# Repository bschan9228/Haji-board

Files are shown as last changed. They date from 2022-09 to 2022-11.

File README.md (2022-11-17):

# Haji Keyboard
The Haji keyboard uses 8-bit shift registers, rather than the typical keyboard matrix cirucit. An advantage in using shift registers is that you can add any amount of keys, instead of being limited by the amount of I/O pins. It uses an STM32F1 chip to communicate to a computer using its native USB interface. I sourced components, designed and fabricated the pcb, soldered, built, and programmed a fully working prototype of a small macropad from scratch.



##PARTS
NOTES:
HOTSWAPPABLE SWITCHES

ICS:
STM32F1
74HC165D,653

MODULES:
UNIFIED C3

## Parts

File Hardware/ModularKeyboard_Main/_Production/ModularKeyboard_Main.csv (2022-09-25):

Comment | Designator | Footprint | LCSC Part #
4.7uF Unpolarized capacitor, small symbol | C1 | C_0402_1005Metric | C189469
100nF Unpolarized capacitor, small symbol | C2,C3,C4,C5,C8 | C_0402_1005Metric | C83056
10nF Unpolarized capacitor, small symbol | C6 | C_0402_1005Metric | C60133
1uF Unpolarized capacitor, small symbol | C7 | C_0402_1005Metric | C92755
12p Unpolarized capacitor, small symbol | C9,C10 | C_0402_1005Metric | C106201
2.2uF Unpolarized capacitor, small symbol | C11,C12 | C_0402_1005Metric | C77002
MountingHole Mounting Hole without connection | H1,H2,H3,H4 | MountingHole_2.2mm_M2 | ~
16MHz Four pin crystal, GND on pins 2 and 4, small symbol | HSE1 | Crystal_SMD_3225-4Pin_3.2x2.5mm | C13738
Conn_01x03 Generic connector, single row, 01x03, script generated (kicad-library-utils/schlib/autogen/connector/) | J1,J2,J3,J4 | PG-3P-2.5 | ~
SM04B-SRSS-TB(LF)(SN) | J5,J6 | JST_SM04B-SRSS-TB(LF)(SN) | C160404
Mount-M2 Generic connector, single row, 01x01, script generated (kicad-library-utils/schlib/autogen/connector/) | MH1,MH2,MH3,MH4 | Generic-Mounthole
OLED | OL1 | OLED_v2 | ~
10k Resistor, small symbol | R1 | R_0402_1005Metric | C144807
22 Resistor, small symbol | R2,R3 | R_0402_1005Metric | C226359
1.5k Resistor, small symbol | R4 | R_0402_1005Metric | C144792
1k Resistor, small symbol | R5 | R_0402_1005Metric | C106235
DNP Resistor, small symbol | R6,R7 | R_0402_1005Metric | C106231
R_Pack04 4 resistor network, parallel topology | RN1,RN2,RN3,RN4 | R_Array_Convex_4x0402 | C326872
SW_SPST Single Pole Single Throw (SPST) switch | SW0,SW1,SW2,SW3,SW4,SW5,SW6,SW7,SW8,SW9,SW10,SW11,SW12,SW13,SW14,SW15 | MX-1U-NoLED | ~
SW_SPST Single Pole Single Throw (SPST) switch | SW16 | SW_SPST_B3U-1000P | C231329
74HC165D,653 | U1,U3 | SOIC127P600X175-16N | C5613
STM32F103CBTx ARM Cortex-M3 MCU, 128KB flash, 20KB RAM, 72MHz, 2-3.6V, 37 GPIO, LQFP-48 | U2 | LQFP-48_7x7mm_P0.5mm | C8304
SPX3819M5-L-3-3 500mA Low drop-out regulator, Fixed Output 3.3V, SOT-23-5 | U4 | SOT-23-5 | C9055

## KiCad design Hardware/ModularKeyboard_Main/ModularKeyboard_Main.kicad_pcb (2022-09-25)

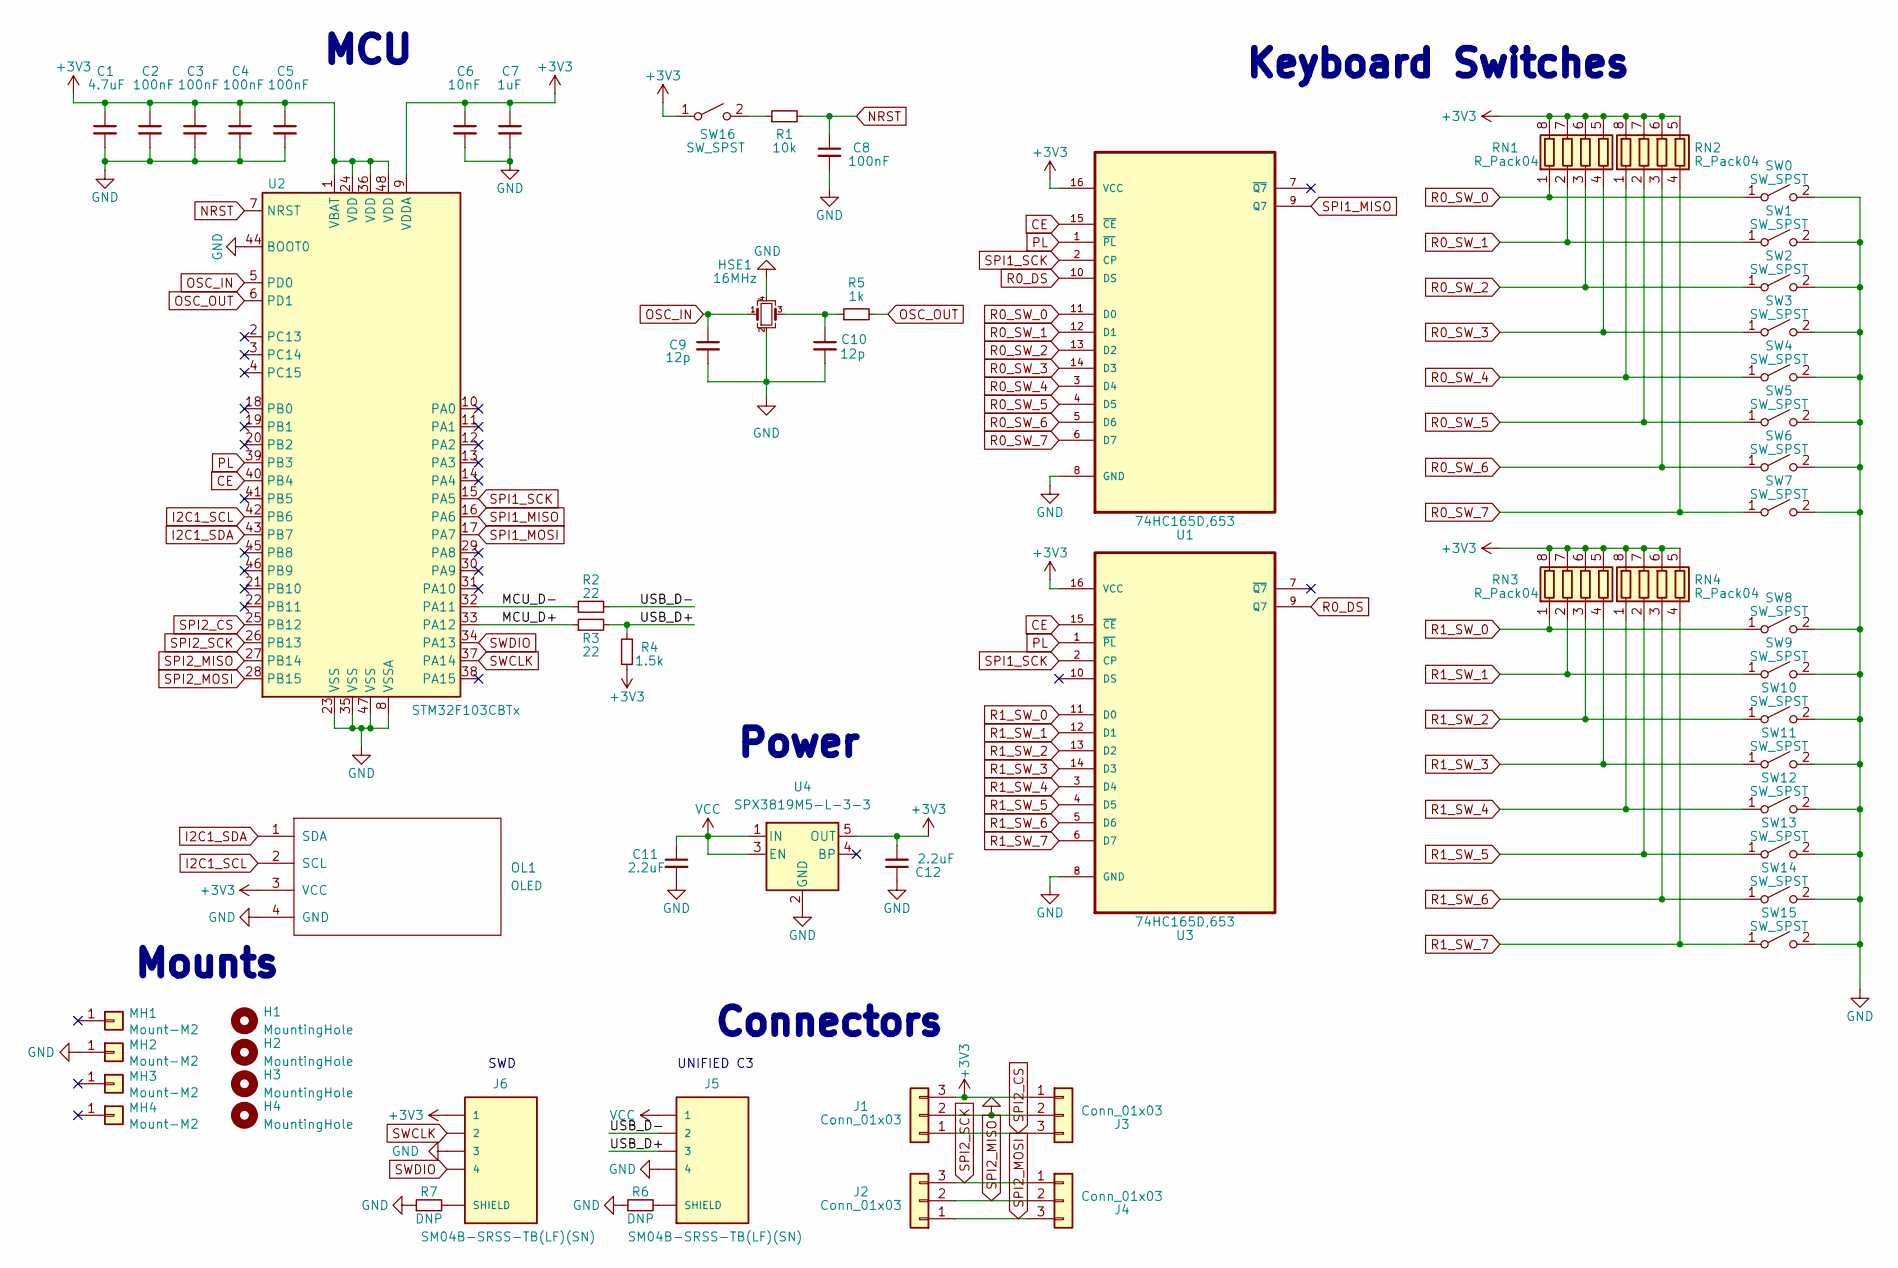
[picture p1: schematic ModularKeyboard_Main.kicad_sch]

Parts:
C1: 4.7uF; C_0402_1005Metric
C2, C3, C4, C5, C8: 100nF; C_0402_1005Metric
C6: 10nF; C_0402_1005Metric
C7: 1uF; C_0402_1005Metric
C9, C10: 12p; C_0402_1005Metric
C11, C12: 2.2uF; C_0402_1005Metric
H1, H2, H3, H4: MountingHole; MountingHole_2.2mm_M2
HSE1: 16MHz; Crystal_SMD_3225-4Pin_3.2x2.5mm
J1, J2, J3, J4: Conn_01x03; PG-3P-2.5
J5, J6: SM04B-SRSS-TB(LF)(SN); JST_SM04B-SRSS-TB(LF)(SN)
MH1, MH2, MH3, MH4: Mount-M2; Generic-Mounthole
OL1: OLED; OLED_v2
R1: 10k; R_0402_1005Metric
R2, R3: 22; R_0402_1005Metric
R4: 1.5k; R_0402_1005Metric
R5: 1k; R_0402_1005Metric
R6, R7: DNP; R_0402_1005Metric
RN1, RN2, RN3, RN4: R_Pack04; R_Array_Convex_4x0402
SW0, SW1, SW2, SW3, SW4, SW5, SW6, SW7, SW8, SW9, SW10, SW11, SW12, SW13, SW14, SW15: SW_SPST; MX-1U-NoLED
SW16: SW_SPST; SW_SPST_B3U-1000P
U1, U3: 74HC165D,653; SOIC127P600X175-16N; MPN 74HC165D,653
U2: STM32F103CBTx; LQFP-48_7x7mm_P0.5mm
U4: SPX3819M5-L-3-3; SOT-23-5

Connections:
+3V3: C1.1, C2.1, C3.1, C4.1, C5.1, C6.1, C7.1, C12.2, J1.3, J3.1, J6.1, OL1.3 (VCC), R4.1, RN1.5 (R4.2), RN1.6 (R3.2), RN1.7 (R2.2), RN1.8 (R1.2), RN2.5 (R4.2), RN2.6 (R3.2), RN2.7 (R2.2), RN2.8 (R1.2), RN3.5 (R4.2), RN3.6 (R3.2), RN3.7 (R2.2), RN3.8 (R1.2), RN4.5 (R4.2), RN4.6 (R3.2), RN4.7 (R2.2), RN4.8 (R1.2), SW16.1 (A), U1.16 (VCC), U2.1 (VBAT), U2.9 (VDDA), U2.24 (VDD), U2.36 (VDD), U2.48 (VDD), U3.16 (VCC), U4.5 (OUT)
/MCU_D+: R3.1, U2.33 (PA12)
/MCU_D-: R2.1, U2.32 (PA11)
/USB_D+: J5.3, R3.2, R4.2
/USB_D-: J5.2, R2.2
CE: U1.15 (~CE), U2.40 (PB4), U3.15 (~CE)
GND: C1.2, C2.2, C3.2, C4.2, C5.2, C6.2, C7.2, C8.2, C9.2, C10.2, C11.2, C12.1, HSE1.2, HSE1.4, J1.2, J3.2, J5.4, J6.3, MH2.1, OL1.4 (GND), R6.1, R7.1, SW0.2 (B), SW1.2 (B), SW2.2 (B), SW3.2 (B), SW4.2 (B), SW5.2 (B), SW6.2 (B), SW7.2 (B), SW8.2 (B), SW9.2 (B), SW10.2 (B), SW11.2 (B), SW12.2 (B), SW13.2 (B), SW14.2 (B), SW15.2 (B), U1.8 (GND), U2.8 (VSSA), U2.23 (VSS), U2.35 (VSS), U2.44 (BOOT0), U2.47 (VSS), U3.8 (GND), U4.2 (GND)
I2C1_SCL: OL1.2 (SCL), U2.42 (PB6)
I2C1_SDA: OL1.1 (SDA), U2.43 (PB7)
NRST: C8.1, R1.2, U2.7 (NRST)
unnamed: C10.1, HSE1.3, R5.1
unnamed: J5.S1 (SHIELD), J5.S2 (SHIELD), R6.2
unnamed: J6.S1 (SHIELD), J6.S2 (SHIELD), R7.2
unnamed: R1.1, SW16.2 (B)
OSC_IN: C9.1, HSE1.1, U2.5 (PD0)
OSC_OUT: R5.2, U2.6 (PD1)
PL: U1.1 (~PL), U2.39 (PB3), U3.1 (~PL)
R0_DS: U1.10 (DS), U3.9 (Q7)
R0_SW_0: RN1.1 (R1.1), SW0.1 (A), U1.11 (D0)
R0_SW_1: RN1.2 (R2.1), SW1.1 (A), U1.12 (D1)
R0_SW_2: RN1.3 (R3.1), SW2.1 (A), U1.13 (D2)
R0_SW_3: RN1.4 (R4.1), SW3.1 (A), U1.14 (D3)
R0_SW_4: RN2.1 (R1.1), SW4.1 (A), U1.3 (D4)
R0_SW_5: RN2.2 (R2.1), SW5.1 (A), U1.4 (D5)
R0_SW_6: RN2.3 (R3.1), SW6.1 (A), U1.5 (D6)
R0_SW_7: RN2.4 (R4.1), SW7.1 (A), U1.6 (D7)
R1_SW_0: RN3.1 (R1.1), SW8.1 (A), U3.11 (D0)
R1_SW_1: RN3.2 (R2.1), SW9.1 (A), U3.12 (D1)
R1_SW_2: RN3.3 (R3.1), SW10.1 (A), U3.13 (D2)
R1_SW_3: RN3.4 (R4.1), SW11.1 (A), U3.14 (D3)
R1_SW_4: RN4.1 (R1.1), SW12.1 (A), U3.3 (D4)
R1_SW_5: RN4.2 (R2.1), SW13.1 (A), U3.4 (D5)
R1_SW_6: RN4.3 (R3.1), SW14.1 (A), U3.5 (D6)
R1_SW_7: RN4.4 (R4.1), SW15.1 (A), U3.6 (D7)
SPI1_MISO: U1.9 (Q7), U2.16 (PA6)
SPI1_MOSI: U2.17 (PA7)
SPI1_SCK: U1.2 (CP), U2.15 (PA5), U3.2 (CP)
SPI2_CS: J1.1, J3.3, U2.25 (PB12)
SPI2_MISO: J2.2, J4.2, U2.27 (PB14)
SPI2_MOSI: J2.1, J4.3, U2.28 (PB15)
SPI2_SCK: J2.3, J4.1, U2.26 (PB13)
SWCLK: J6.2, U2.37 (PA14)
SWDIO: J6.4, U2.34 (PA13)
VCC: C11.1, J5.1, U4.1 (IN), U4.3 (EN)

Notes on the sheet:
Keyboard Switches
Connectors
SWD
UNIFIED C3
Power
Mounts
MCU

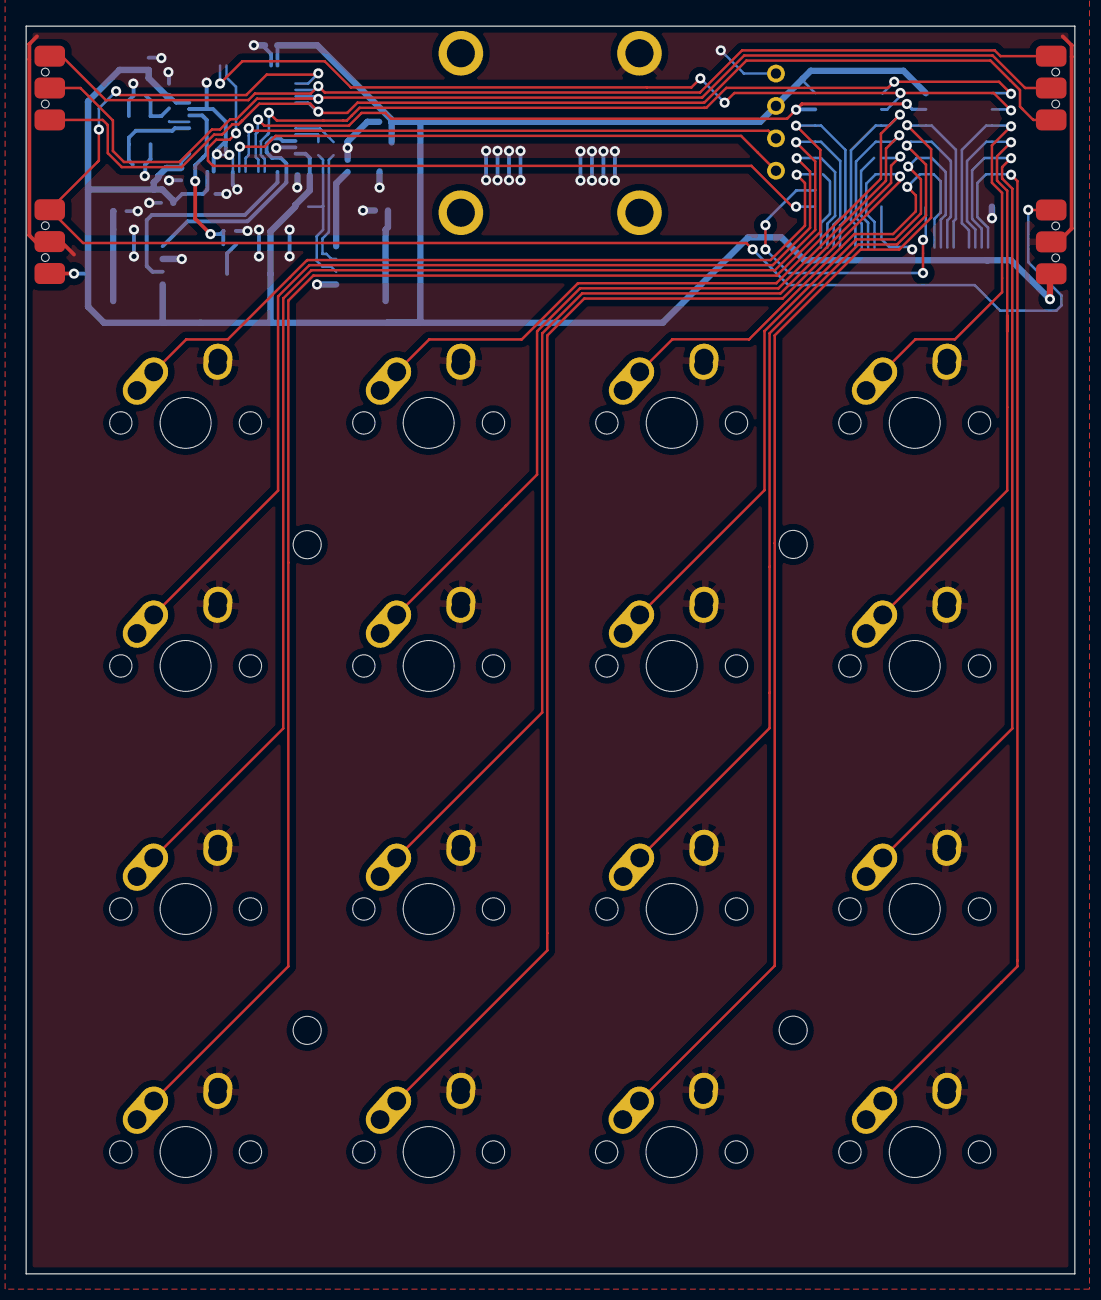
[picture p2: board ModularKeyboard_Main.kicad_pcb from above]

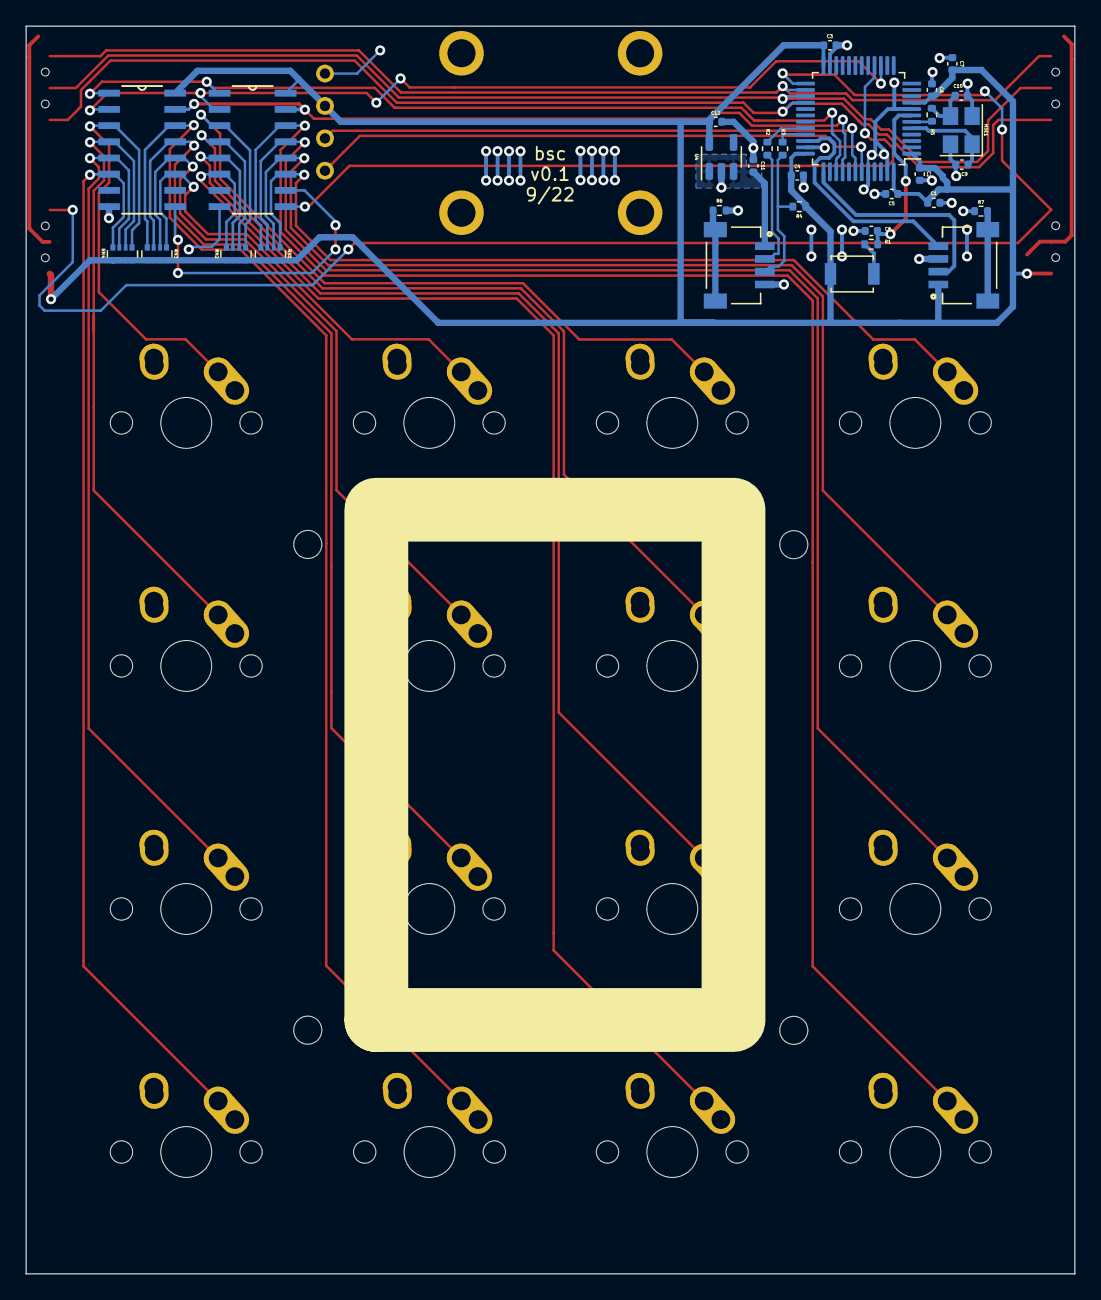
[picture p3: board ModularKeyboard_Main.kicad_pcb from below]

Board: 2 copper layers, 82.2 x 97.8 mm, 60 parts (31 on the bottom side), 43 nets.

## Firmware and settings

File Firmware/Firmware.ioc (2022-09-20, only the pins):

Mcu.UserName=STM32F103CBTx
PA11.Signal=USB_DM
PA12.Signal=USB_DP
PA13.Signal=SYS_JTMS-SWDIO
PA14.Signal=SYS_JTCK-SWCLK
PA5.Signal=SPI1_SCK
PA6.Signal=SPI1_MISO
PA7.Signal=SPI1_MOSI
PB12.GPIO_Label=SPI2_CS
PB12.Signal=GPIO_Output
PB13.Signal=SPI2_SCK
PB14.Signal=SPI2_MISO
PB15.Signal=SPI2_MOSI
PB3.GPIO_Label=CE
PB3.Signal=GPIO_Output
PB4.GPIO_Label=PL
PB4.Signal=GPIO_Output
PB6.Signal=I2C1_SCL
PB7.Signal=I2C1_SDA
PD0-OSC_IN.Signal=RCC_OSC_IN
PD1-OSC_OUT.Signal=RCC_OSC_OUT

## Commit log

2022-09-19 Finished initial sketches
    [ModularKeyboard_Main.kicad_pcb, ModularKeyboard_Main.kicad_sch]
2022-09-19 Completed most wiring
    [ModularKeyboard_Main.kicad_pcb, ModularKeyboard_Main.kicad_sch]
2022-09-20 Completed wiring v0.1 -- add bom
    [ModularKeyboard_Main.kicad_pcb, ModularKeyboard_Main.kicad_sch]
2022-09-25 Completed v0.1
    [ModularKeyboard_Main-B_Cu.gbr, ModularKeyboard_Main-B_Mask.gbr, ModularKeyboard_Main-B_Paste.gbr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]
